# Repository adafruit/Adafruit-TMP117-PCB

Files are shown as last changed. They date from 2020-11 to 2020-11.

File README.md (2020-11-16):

## Adafruit TMP117 High-accuracy Temperature Sensor PCB

<a href="http://www.adafruit.com/products/4821"><br/>
Click here to purchase one from the Adafruit shop</a>

PCB files for the Adafruit TMP117 High-accuracy Temperature Sensor. 

Format is EagleCAD schematic and board layout
* https://www.adafruit.com/product/4821

### Description

The TMP117 Precision Temperature Sensor is an I2C temperature sensor that will help you easily add temperature measurement and adjustment to your project. In addition to the obvious support for reading the temperature, the TMP117 can also monitor the temperature and alert you when corrective action needs to be taken. 

With 16-bit measurement resolution and ±0.1°C accuracy, as well as high and low temperature alerts and interrupt support, and hardware support required for NIST traceability, this temperature sensor is perfect for applications where you need to keep a close eye on temperature. The manufacturer, Texas Instruments even suggest it for use in sensitive applications like thermostats and cold chain asset tracking or even gas and heat meters!

To make using it as easy as possible, we’ve put the TMP117 on a breakout PCB  in our Stemma QT form factor with a sprinkle of support circuitry to give you options when testing. You can either use a bread board or the Stemma QT connectors, and it is compatible with 5V voltage levels as commonly found on Arduinos as well as 3.3V logic used by many other boards like the Raspberry Pi or our Feathers. To get started, all you need to do is look over the Pinouts page for familiarize yourself with the board, and then use the Arduino or Python & CircuitPython pages for instructions on how to wire up the TMP117 to your board, as well as libraries and example code to get you started.

### License

Adafruit invests time and resources providing this open source design, please support Adafruit and open-source hardware by purchasing products from [Adafruit](https://www.adafruit.com)!

Designed by Limor Fried/Ladyada for Adafruit Industries.

Creative Commons Attribution/Share-Alike, all text above must be included in any redistribution. 
See license.txt for additional details.

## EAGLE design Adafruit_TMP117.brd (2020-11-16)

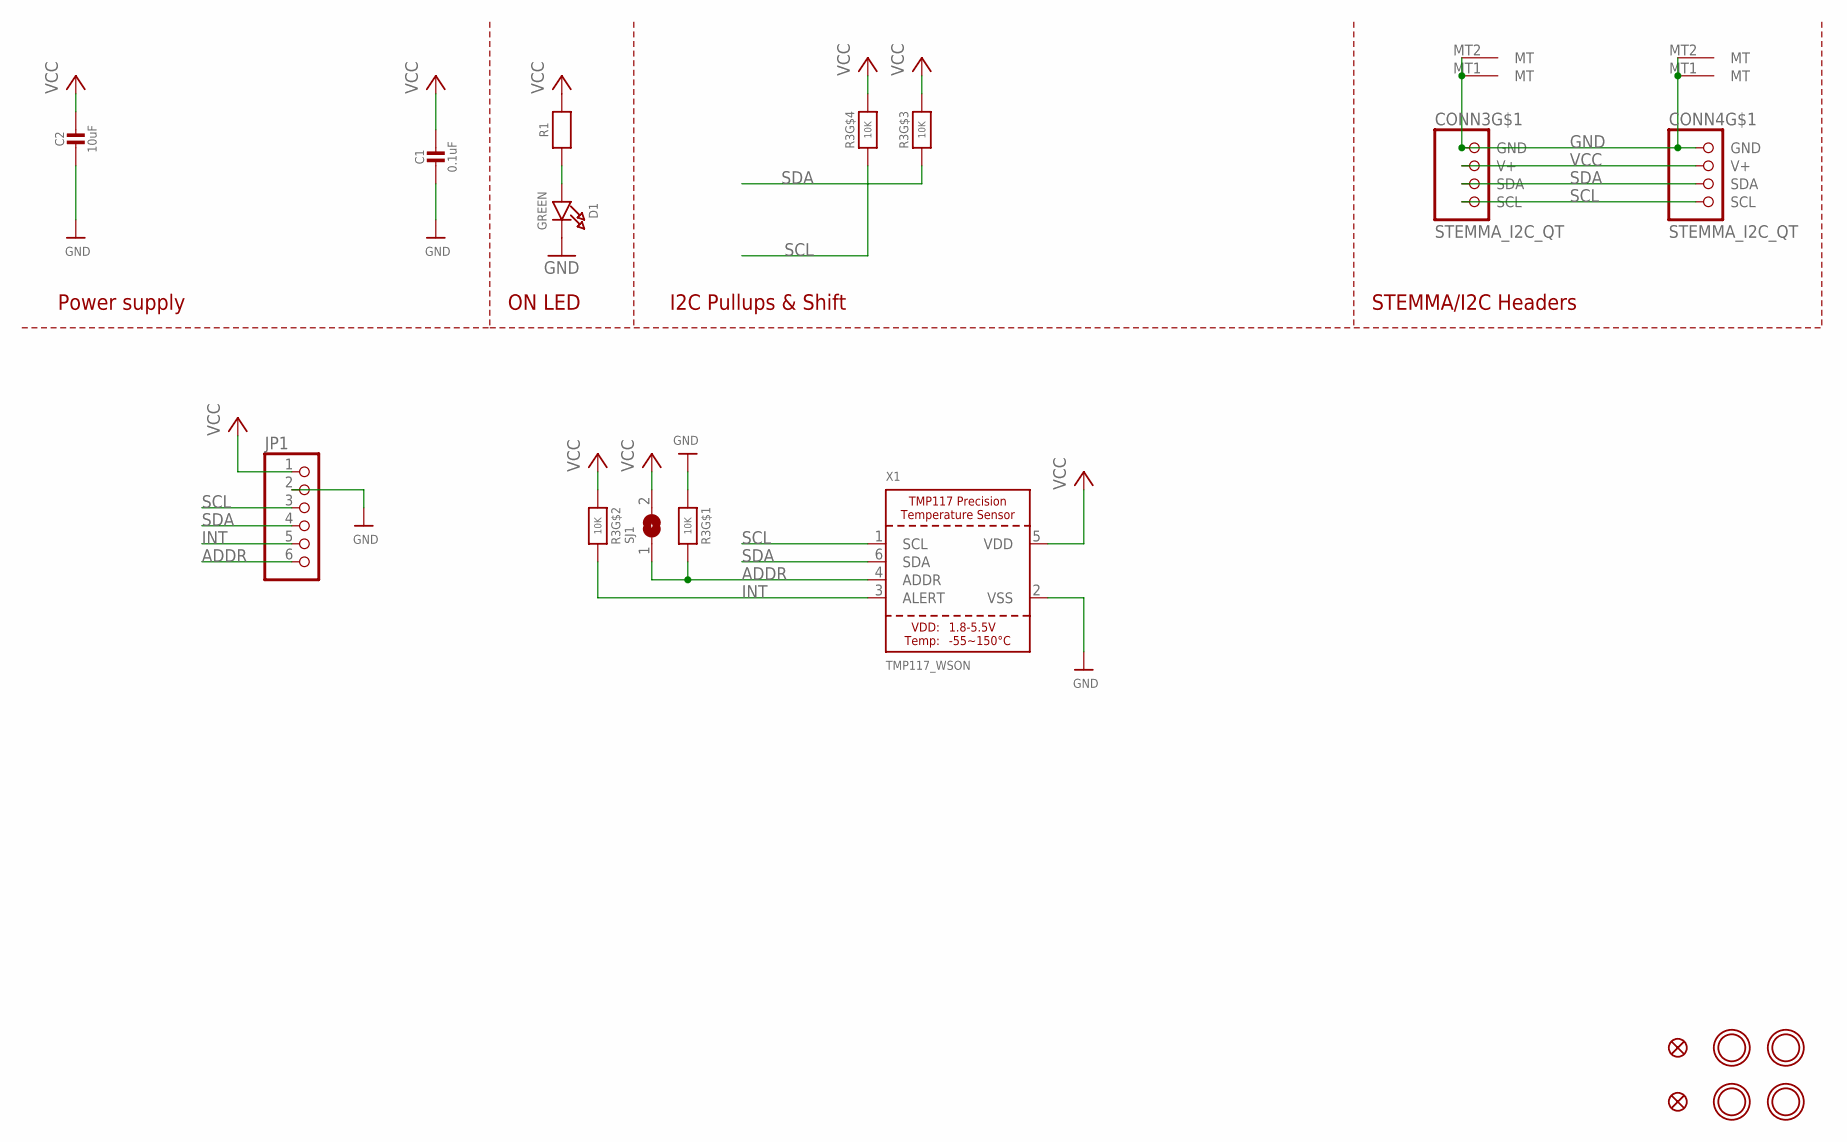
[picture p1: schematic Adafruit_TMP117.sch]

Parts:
C1: 0.1uF; 0603-NO
C2: 10uF; 0805-NO
CONN3, CONN4: STEMMA_I2C_QT; JST_SH4
D1: GREEN; CHIPLED_0603_NOOUTLINE
FID3, FID4: FIDUCIAL_1MM
JP1: HEADER-1X670MIL; 1X06_ROUND_70
R1: RESISTOR_0603_NOOUT; 0603-NO
R3: 10K; RESPACK_4X0603
SJ1: SOLDERJUMPER; SOLDERJUMPER_ARROW_NOPASTE
U$1, U$17, U$19, U$21: MOUNTINGHOLE2.5; MOUNTINGHOLE_2.5_PLATED
X1: TMP117_WSON; WSON-6

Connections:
ADDR: JP1.6, R3.8 (2), SJ1.1, X1.4 (ADDR)
GND: C1.2, C2.2, CONN3.1 (GND), CONN3.MT1 (MT), CONN3.MT2 (MT), CONN4.1 (GND), CONN4.MT1 (MT), CONN4.MT2 (MT), D1.C, JP1.2, R3.1, X1.2 (VSS)
INT: JP1.5, R3.7 (2), X1.3 (ALERT)
unnamed: D1.A, R1.1
SCL: CONN3.4 (SCL), CONN4.4 (SCL), JP1.3, R3.4 (1), X1.1 (SCL)
SDA: CONN3.3 (SDA), CONN4.3 (SDA), JP1.4, R3.3 (1), X1.6 (SDA)
VCC: C1.1, C2.1, CONN3.2 (V+), CONN4.2 (V+), JP1.1, R1.2, R3.2 (1), R3.5 (2), R3.6 (2), SJ1.2, X1.5 (VDD)

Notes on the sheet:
I2C Pullups & Shift
STEMMA/I2C Headers
ON LED
Power supply

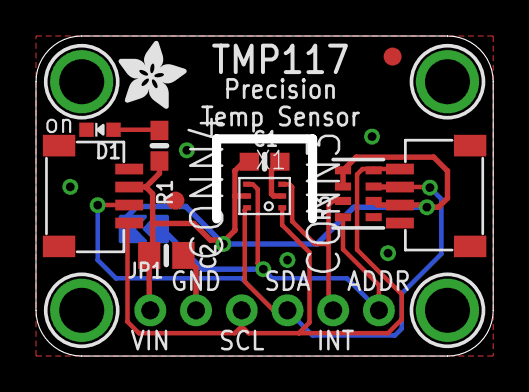
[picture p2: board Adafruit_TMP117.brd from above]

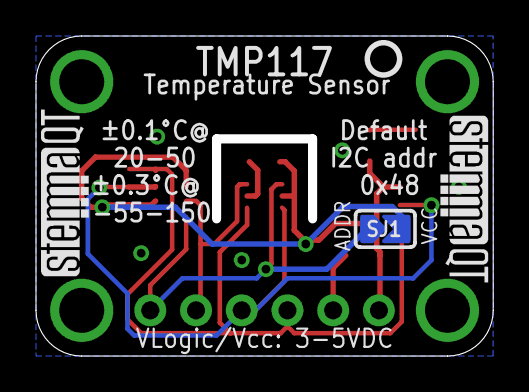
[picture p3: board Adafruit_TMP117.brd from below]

Board: 2 copper layers, 25.4 x 17.8 mm, 20 parts (4 on the bottom side), 7 nets.

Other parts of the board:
U$22: ADAFRUIT_3.5MM
U$25: PCBFEAT-REV-040
U$30, U$31: STEMMAQT

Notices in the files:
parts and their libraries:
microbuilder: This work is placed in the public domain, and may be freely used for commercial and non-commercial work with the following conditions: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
